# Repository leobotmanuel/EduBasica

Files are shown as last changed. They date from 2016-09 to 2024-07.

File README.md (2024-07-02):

# EduBasica


EDUBASICA es una tarjeta de prototipado rápido para conectar a Arduino. Incluye componentes electrónicos básicos para gran variedad de prácticas y proyectos. Es una tarjeta multipropósito con componentes electrónicos incluidos que puedes usar para fabricar un robot, controlar un sistema de poleas, activar barreras, comunicar dispositivos bluetooth, y todo lo que te puedas imaginar.

 www.arduino.org -- www.arduino.cc

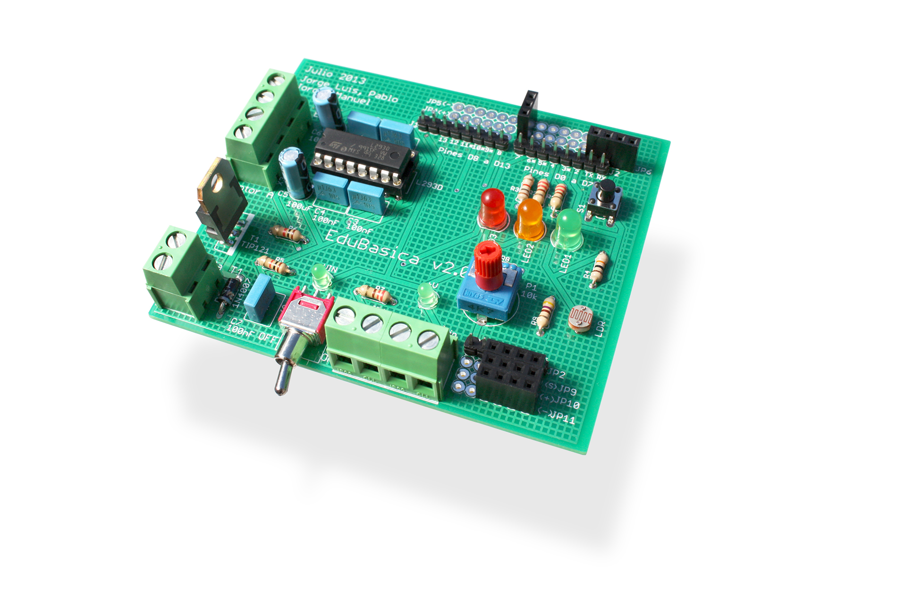
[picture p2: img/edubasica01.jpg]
 EduBasica -- www.practicasconarduino.com

# Conexiones EduBasica con Arduino

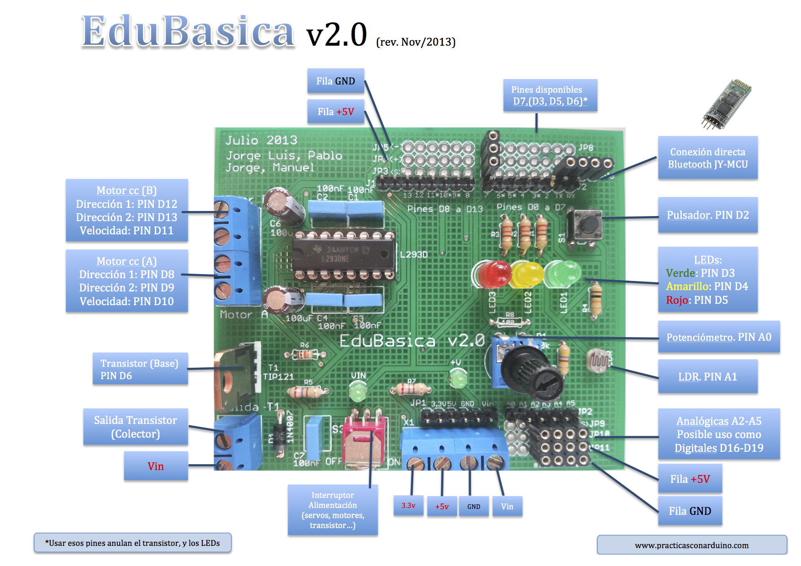
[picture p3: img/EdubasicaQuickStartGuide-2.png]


# Prácticas de programación y electrónica 
# con Arduino-EduBasica

Archivo en pdf de 4ºESO

https://www.dropbox.com/s/mtubbro328of7fd/PracticasConArduino2-2.pdf?dl=0
# Autores
Pablo E. García -- https://www.linkedin.com/in/pablo-evaristo-garc%C3%ADa-palacios-083a5483

Manuel Hidalgo -- https://es.linkedin.com/in/manuel-hidalgo-díaz-b95b467b

Jorge Luis Loza -- https://es.linkedin.com/in/jorgeluisloza

Jorge Muñoz -- https://es.linkedin.com/in/jorge-mu%C3%B1oz-8a641160/es

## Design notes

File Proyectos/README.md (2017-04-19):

# Proyectos con EduBasica


En esta sección tenemos proyectos con EduBasica-Arduino.
# Maqueta de Control de barrera de parking
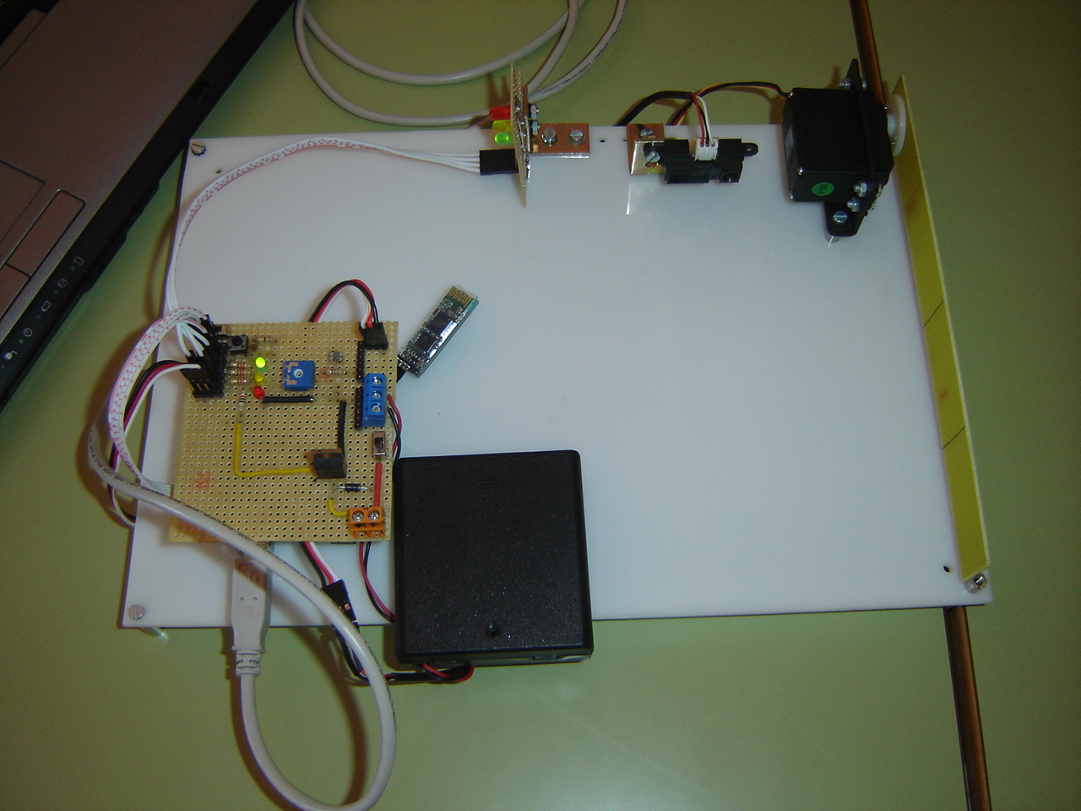
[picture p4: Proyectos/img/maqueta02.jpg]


Este proyecto es una actualización del realizado en el Taller de Robótica Educativa en el IES Pintor Rafael Requena de Caudete-Albacete en el curso 2011-2012.

Video: https://www.youtube.com/watch?v=ucT549aUI94

Presentación: http://platea.pntic.mec.es/~mhidalgo/page5.html

Acceso a la actualización: https://github.com/leobotmanuel/EduBasica/blob/master/Proyectos/controlBarreraParking/README.md
# Maqueta de Control de temperatura
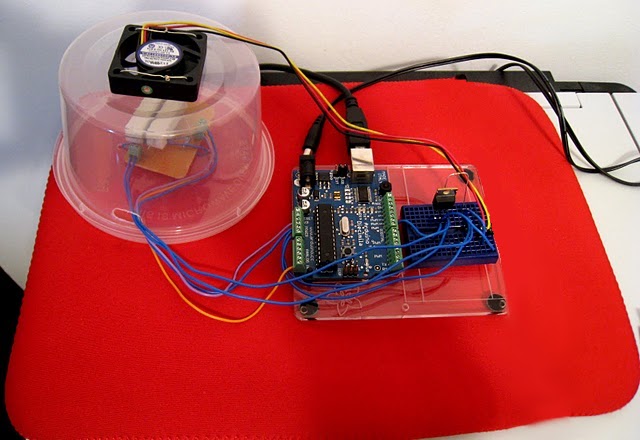
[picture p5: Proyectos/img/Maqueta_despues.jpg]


Este proyecto se basa en la colaboración de Igor R., Alberto Yedra y LeoBot (Manuel) por la fecha de julio del 2011 en la Campus Party de Valencia.

Fuente: http://real2electronics.blogspot.com.es/2011/07/maqueta-de-control-pid-con-arduino.html
# Robot imprimibles
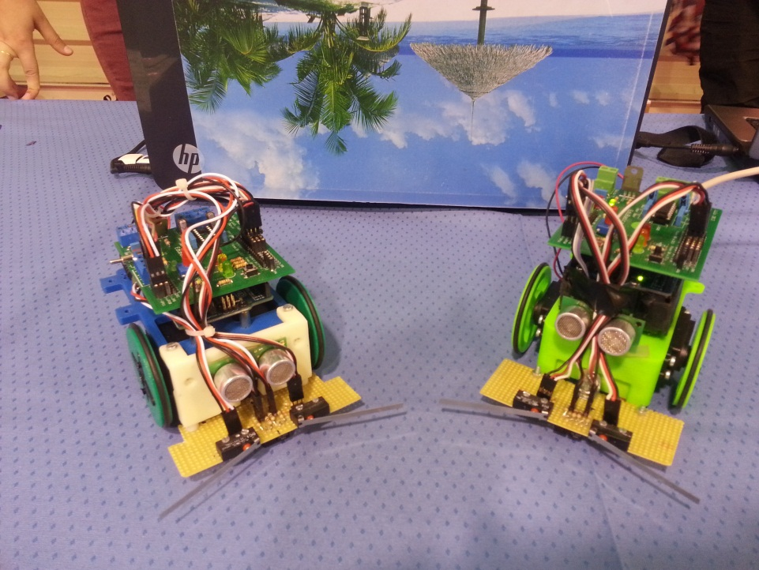
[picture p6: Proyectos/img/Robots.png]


Proyectos de robots imprimibles que tanta aceptación ha tenido en el aula como trabajo para desarrollar los contenidos de electrónica, control, programación y documentación digital.

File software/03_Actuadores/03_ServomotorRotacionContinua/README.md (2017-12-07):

# Servomotor de rotación continua
El servomotor de rotación continua es un servomotor que gira 360º, la velocidad y sentido de giro es controlada por la señal PWM (modulada por anchura de pulso) generada por un microcontrolador.

Señal de control PWM.

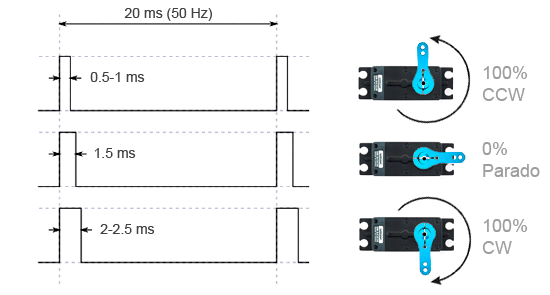
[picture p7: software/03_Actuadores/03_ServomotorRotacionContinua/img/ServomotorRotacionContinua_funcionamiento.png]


Velocidad del servomotor de rotación continua. 

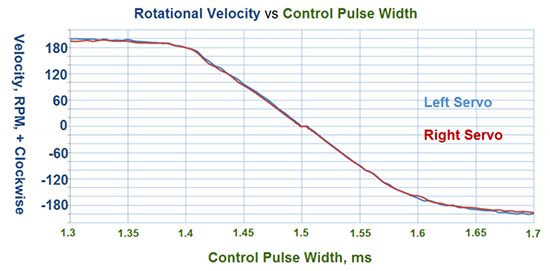
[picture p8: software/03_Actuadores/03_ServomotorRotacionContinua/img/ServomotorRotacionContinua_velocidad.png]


Fuente: [Luis LLamas](https://www.luisllamas.es/controlar-un-servo-de-rotacion-continua-con-arduino)

El servomotor de rotación continua tiene los mismos elementos que el servomotor, diferenciandose sólo en que la resistencia variable es fija. Este cambio hace que se llame "servomotor trucado".

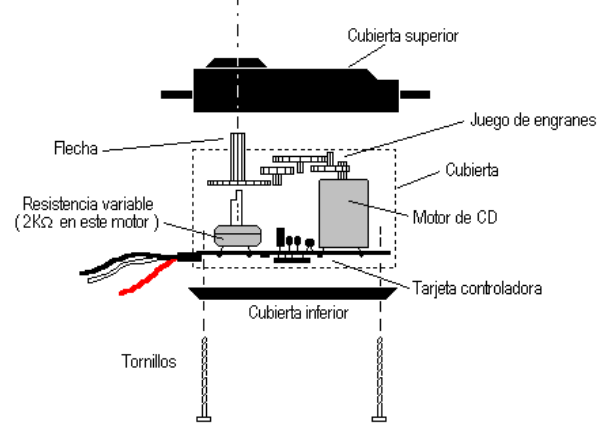
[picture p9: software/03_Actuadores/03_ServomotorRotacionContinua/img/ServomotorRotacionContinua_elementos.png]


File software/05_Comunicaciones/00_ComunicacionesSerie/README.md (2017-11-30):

# Comunicaciones. Puerto serie (USB)
El puerto serie de Arduino se usa para transmitir y recibir datos de otros dispositivos como un PC, teléfono móvil, tablet o microcontrolador.

El puerto serie del Arduino Uno usa los pins 0(RX) y 1(TX). Estos están conectados al controlador FTDI (ATmega 16u2) que es el que permite la traducción del formato serie TTL a USB. Estos pins no pueden ser utilizados mientras se usa la comunicación serie.
Más información del [puerto serie](http://diymakers.es/usando-el-puerto-serie-del-arduino/), la tabla de códigos ASCII se encuentra en la información.

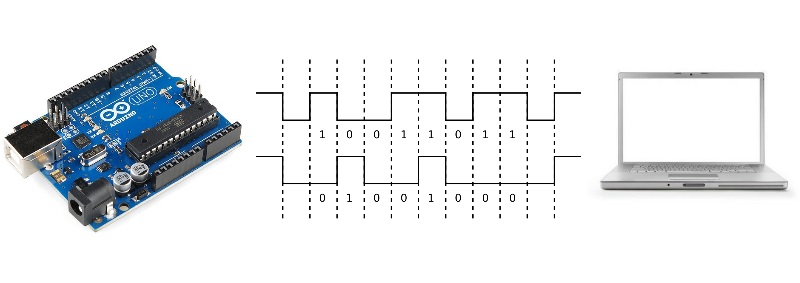
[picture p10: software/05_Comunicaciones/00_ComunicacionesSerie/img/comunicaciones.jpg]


Los programas para aprender el funcionamiento de las comunicaciones por el puerto serie. Son el mismo programa peero con diferente
estructura de control.
- prog11_serie01.bly
- prog11_serie01b.bly

# Actividad
- Añadid las instrucciones necesarias para controlar todos los leds por el puerto serie.

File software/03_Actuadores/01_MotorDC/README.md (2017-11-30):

# Motores de corriente continua
Los motores de corriente continua (motores DC) son unos de los actuadores más utilizados en Robótica Educativa. 
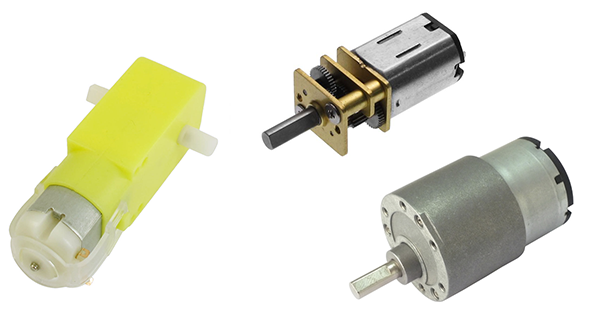
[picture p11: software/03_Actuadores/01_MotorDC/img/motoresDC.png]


Su funcionamiento se basa en el alineamiento de dos campos magnéticos. 
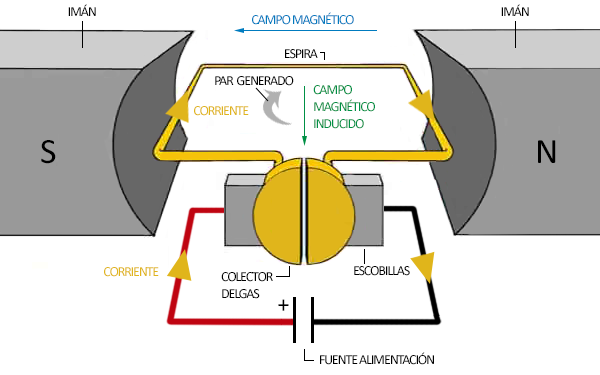
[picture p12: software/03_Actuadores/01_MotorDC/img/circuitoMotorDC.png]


Fuente: [Luis LLamas](http://www.luisllamas.es/2016/08/tipos-motores-rotativos-proyectos-arduino/)

Con EduBasica se puede controlar dos motores DC, utilizando el circuito integrado L293.

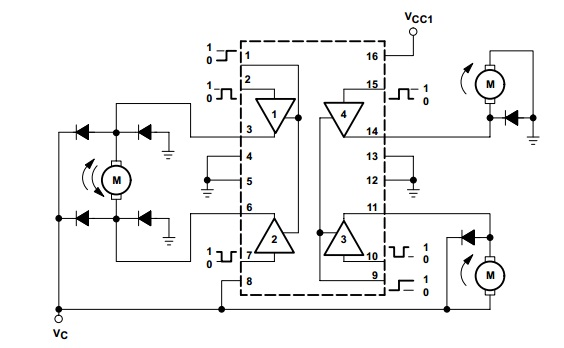
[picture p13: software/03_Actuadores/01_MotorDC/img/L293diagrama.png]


[Más información:](https://learn.adafruit.com/adafruit-arduino-lesson-15-dc-motor-reversing?view=all)

Los programa para aprender su funcionamiento con EduBasica:
- prog08_motorA01.bly
- prog08_motorA02.bly
- prog08_motorA03.bly
- prog08_motorA4.bly

# Actividad

- Modificad y añadid el programa prog08_motorA4.bly para que se encienda el led verde cuando avanza, el led rojo cuando retrocede y el amarillo parpadee cuando esté parado.

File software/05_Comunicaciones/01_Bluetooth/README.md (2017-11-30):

# Bluetooth
El Bluetooth es un estándar de comunicación inalámbrica que permite la transmisión de datos a través de radiofrecuencia en la banda de 2,4 GHz. 

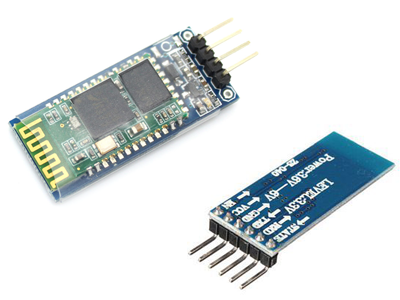
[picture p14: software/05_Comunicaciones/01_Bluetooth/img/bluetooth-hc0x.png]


El módulo de bluetooth en EduBasica se conecta en un zócalo de 4 pines.
-    El pin de transmisión del Bluetooth Tx se conecta al de recepción de Arduino Rx.
-    El pin de recepción del Bluetooth Rx se conecta al de transmisión de Arduino Tx.
-    El pin Vcc del Bluetooth al (+).
-    El pin GND del Bluetooth al (-)
**IMPORTANTE:**
En el momento de cargar el programa desde el Visualino a la placa Arduino hay que desconectar el módulo de Bluetooth para que no interfiera.

Para ello utilizaremos un módulo HC-06 para Arduino y la aplicación para Android Bluecontrol.

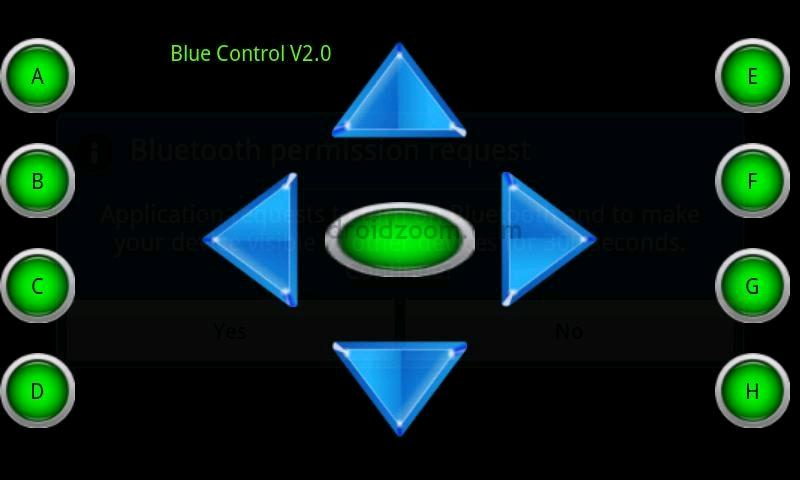
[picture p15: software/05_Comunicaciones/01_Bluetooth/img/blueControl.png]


Ambos dispositivos, módulo Bluetooth y telefóno móvil o tablet, se tienen que emparejar y compartir una contraseña para que los datos puedan intercambiarse. Por defecto, estos módulos tienen la contraseña 1234. Normalmente el módulo de bluetooth tiene un LED que parpadea cuando se está intentando conectar con el móvil. Una vez hecho, la luz del LED permanece fija.

El programa, que tenemos que cargar en Arduino, para aprender su funcionamiento con Visualino:

- prog11_bluetooth.bly

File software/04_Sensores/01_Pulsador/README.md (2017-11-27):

# Pulsador, sensor digital.
El pulsador es un objeto tecnológico simple y nos da dos niveles de tensión alto (HIGH) y bajo (LOW).

El pulsador en EduBasica se utiliza para aprender a leer las [entradas digitales](https://www.luisllamas.es/entradas-digitales-en-arduino/), que tiene el estado de activo (1, lógico)
o no activo (0, lógico) como son: final de carrera, sensor de presencia, sensor a distancia determinada,...

El circuito del pulsador en EduBasica es el siguiente:

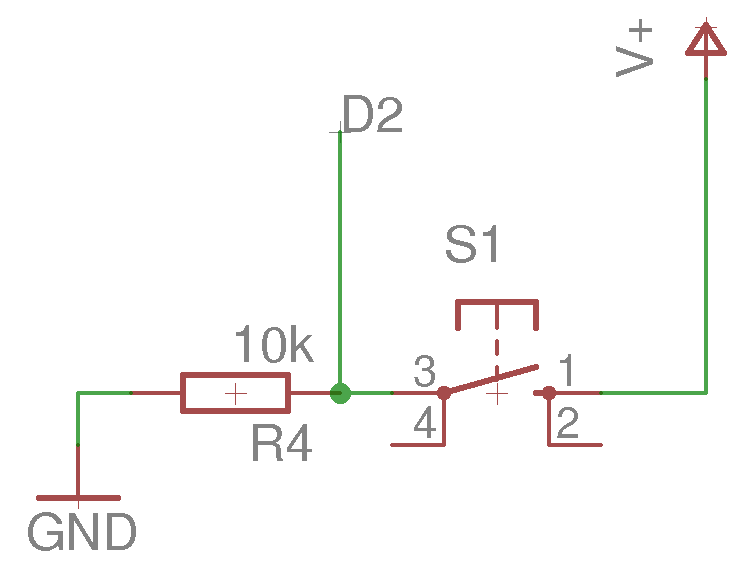
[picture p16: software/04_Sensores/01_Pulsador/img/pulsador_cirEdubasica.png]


El programa para observar su funcionamiento con Visualino:

- prog03_Pulsador.bly

Observad y comprobad que:

- Si el pulsador no está pulsador el LED rojo está apagado.

- Si el pulsador está pulsado el LED rojo está encendido.

# Actividad
Modificad las dos estructuras de control **if**, en el prog03_pulsador.bly, por una estructura de control **if-else**.

Más información [wwww.luisllamas.com](https://www.luisllamas.es/leer-un-pulsador-con-arduino/)

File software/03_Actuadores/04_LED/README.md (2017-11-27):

# LED, actuador de salida luminoso.
El LED es un objeto tecnológico simple luminoso que permite dar información de un evento si está activado o desactivado.
Para más información de su funcionamiento y precauciones a tener en cuenta, consultad [aquí](https://www.luisllamas.es/encender-un-led-con-arduino/)

El LED en EduBasica se utiliza para aprender a programar las [salidas digitales](https://www.luisllamas.es/salidas-digitales-en-arduino/)

El circuito de los LEDs en EduBasica es el siguiente:

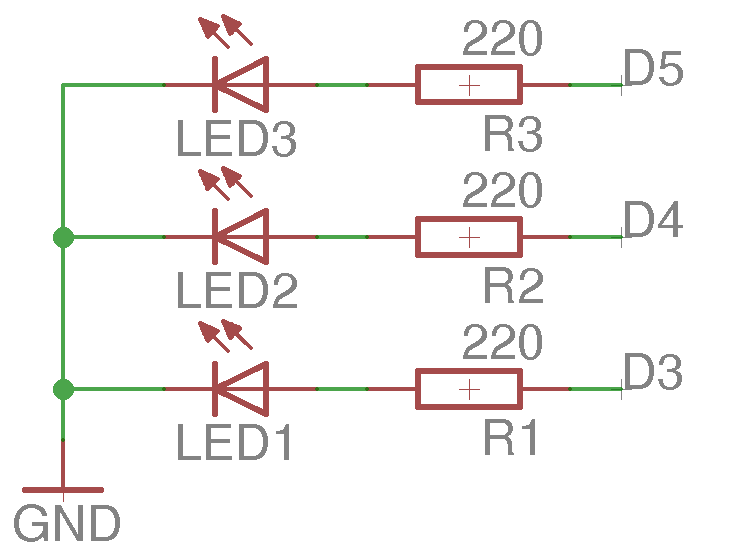
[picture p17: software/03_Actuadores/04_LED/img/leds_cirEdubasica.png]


El programa para aprender a programar las salidas digitales con Visualino:

- prog01_Parpadeo.bly
- prog02_Secuencia.bly

# Actividad
Modificad los programas anteriores para crear secuencias diferentes.

Web de ampliación de información [www.luisllamas.es](https://www.luisllamas.es)

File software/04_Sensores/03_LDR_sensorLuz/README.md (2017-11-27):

# LDR (light-dependent resistor) sensor de luz
El sensor LDR es un sensor resistivo (fotoresistor), es decir que su resistencia eléctrica varía en función de la luz que recibe.
Es un sensor analógico por lo que, para leer sus medidas, tenemos que conectarlo a una entrada analógica de Arduino.
Si tapamos o acercamos el sensor a la luz veremos cómo cambian las medidas a través del monitor serie. 
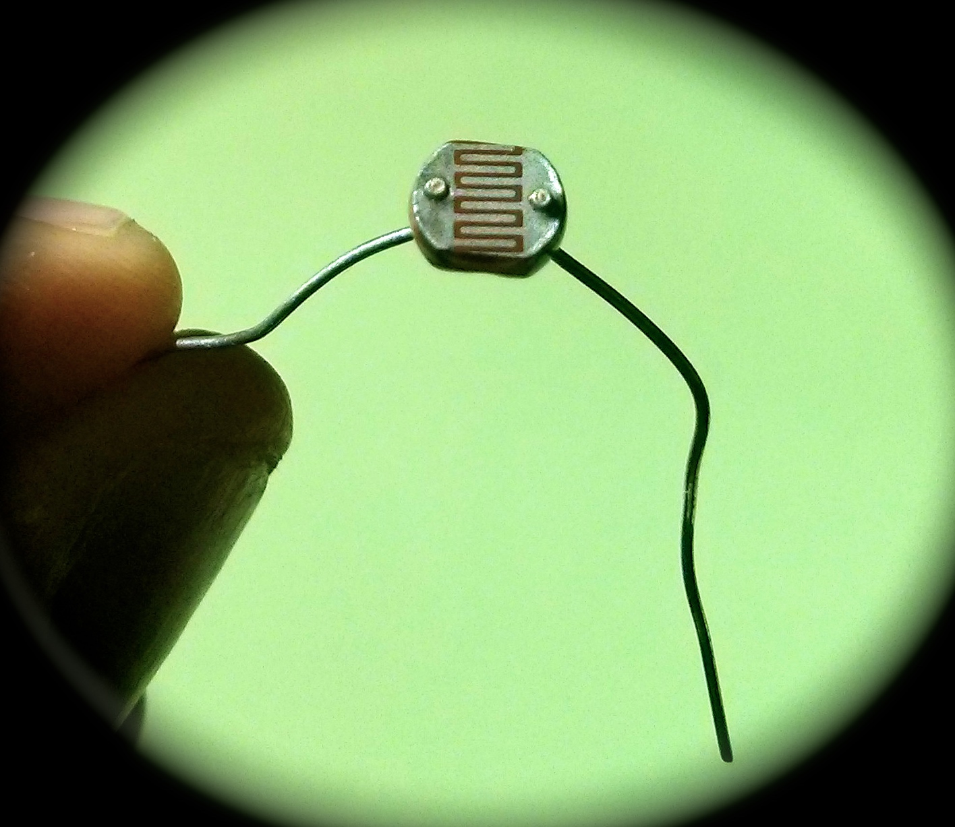
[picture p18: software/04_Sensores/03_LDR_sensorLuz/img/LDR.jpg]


El circuito del sensor LDR en EduBasica es el siguiente:

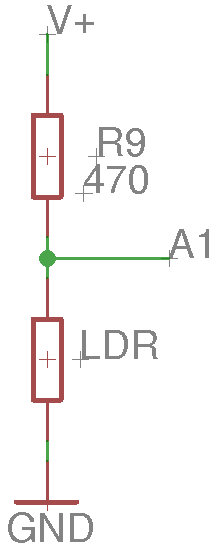
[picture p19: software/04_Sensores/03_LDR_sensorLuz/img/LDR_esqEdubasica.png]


El programa para observar su funcionamiento con Visualino:

- prog06_sensorLDR.bly

A través del monitor serie se comprueba que:

- Si recibe luz el valor leído es bajo.

- Si no recibe luz el valor leído es alto.

# Actividad
Programar el encendido de un led con el LDR (simulación día-noche).

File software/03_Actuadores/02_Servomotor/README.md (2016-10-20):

# Servomotor
El servomotor es un actuador muy utilizado en los proyectos de robótica. 
Un servomotor recibe una señal PWM (modulada por anchura de pulso) generada por un microcontrolador, que posiciona el eje del
servomotor mediante su electrónica de control en un ángulo determinado.

Señal de control PWM.

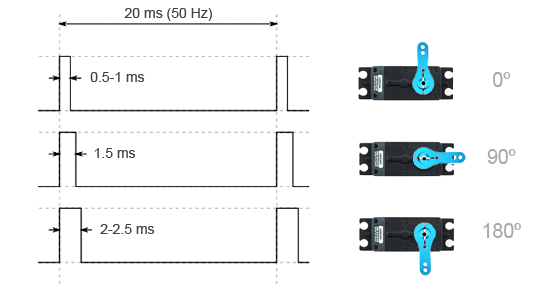
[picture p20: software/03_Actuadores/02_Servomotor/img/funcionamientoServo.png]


Tipos de servomotores. 

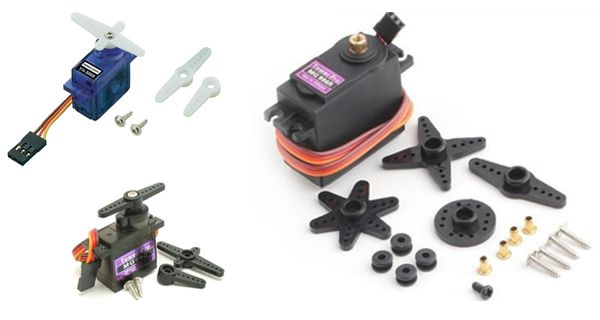
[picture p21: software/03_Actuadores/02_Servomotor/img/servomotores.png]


Elementos de servomotores.

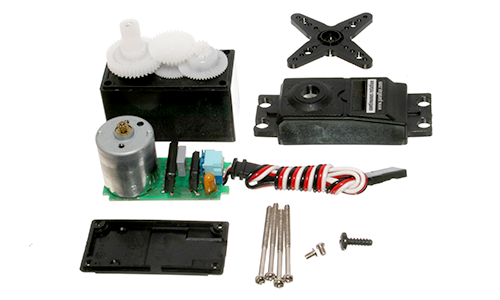
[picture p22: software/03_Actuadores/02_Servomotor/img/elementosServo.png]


Fuente: Luis LLamas
http://www.luisllamas.es/2016/08/tipos-motores-rotativos-proyectos-arduino/

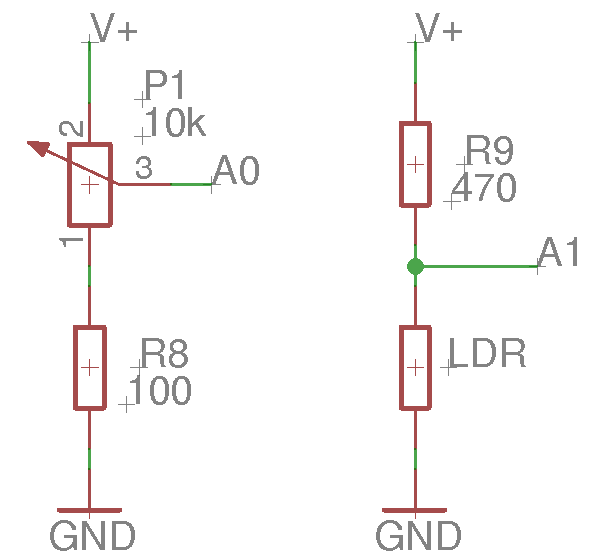
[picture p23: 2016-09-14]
esquemas/img/EntradasAnalogicas.png

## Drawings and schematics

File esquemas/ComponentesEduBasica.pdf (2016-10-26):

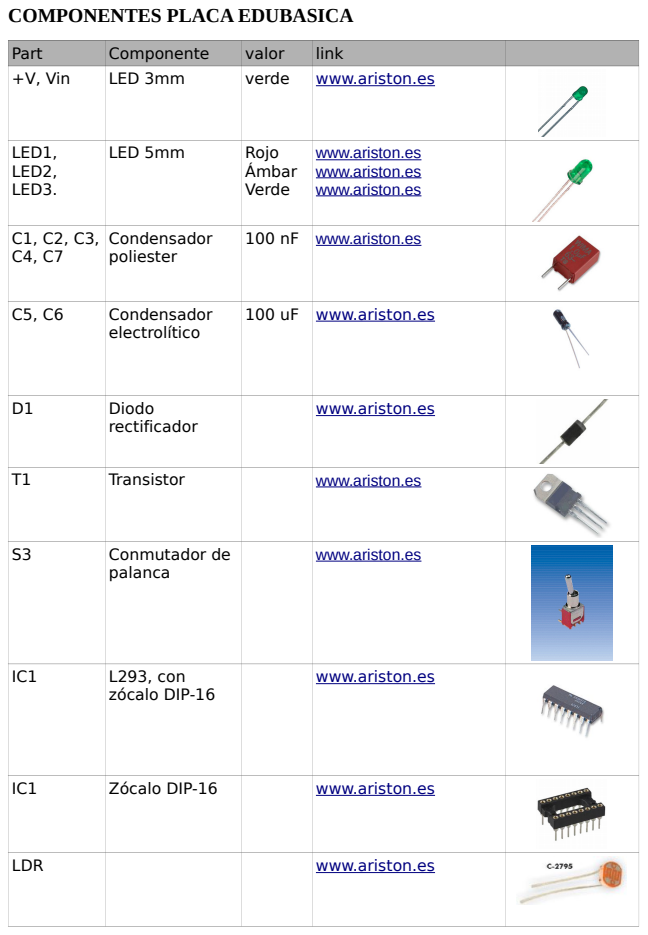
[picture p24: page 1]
Part; Componente; valor; link; +V, Vin; LED 3mm; verde; www.ariston.es; LED1, LED2, LED3.; LED 5mm; Rojo; Ámbar Verde; Condensador poliester; Condensador; electrolítico; Diodo; rectificador; Transistor; Conmutador de; palanca; L293, con; zócalo DIP-16; Zócalo DIP-16; LDR

COMPONENTES PLACA EDUBASICA

www.ariston.es (http://www.ariston.es/producto/l1503it-rohs-kingbright-led-rojo-5mm-32-200mcd-27576.aspx)
www.ariston.es (http://www.ariston.es/producto/l456byd-rohs-diodo-led-intermitente-amarillo-5mm-25150.aspx)
www.ariston.es (http://www.ariston.es/producto/l53gd12-rohs-kingbright-led-verde-12v-5mm-5-32mcd-24086.aspx)

100 nF www.ariston.es (http://www.ariston.es/producto/wh100k100-rohs-wima-mks2-100nf-100v-10-r-5mm-polies-metal-radial-26507.aspx)

100 uF www.ariston.es (http://www.ariston.es/producto/jm100u16-rohs-cond-mini-elec-rad-85c-16v-100uf-6x7-r-25-23860.aspx)

www.ariston.es (http://www.ariston.es/producto/1n4007hb-rohs-1n4007-do-41-1a-1000v-rectifier-diode-hy-46159.aspx)

www.ariston.es (http://www.ariston.es/producto/it0610-rohs-conm-sub-mini-acodado-palanca-2p-1c-on-none-on-ci-13305.aspx)

www.ariston.es

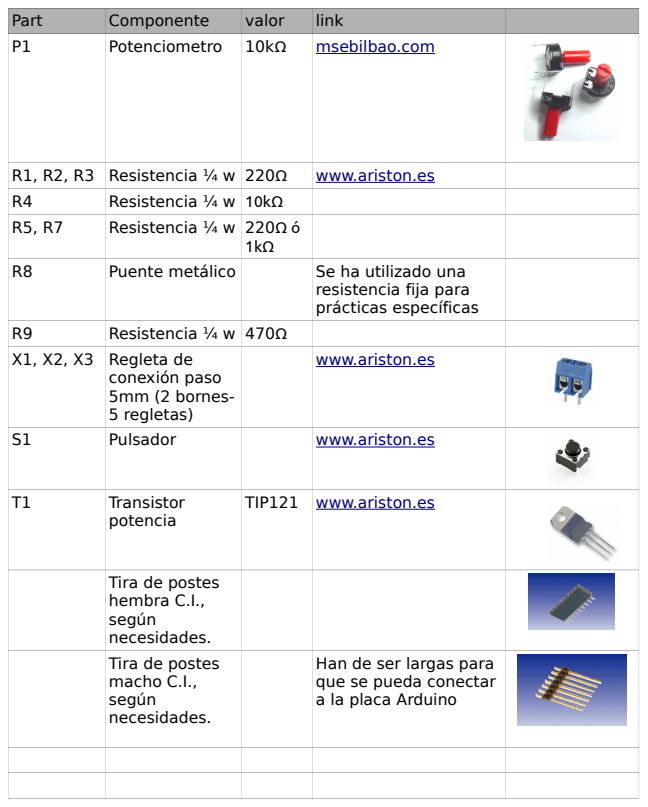
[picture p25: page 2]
Part; Componente; valor; link; Potenciometro; msebilbao.com; R1, R2, R3 Resistencia ¼ w 220Ω; www.ariston.es; Resistencia ¼ w 10kΩ; Resistencia ¼ w 220Ω ó; Puente metálico; Se ha utilizado una; Resistencia ¼ w 470Ω; X1, X2, X3 Regleta de conexión paso 5mm (2 bornes- 5 regletas); Pulsador; Transistor; potencia

resistencia fija para
prácticas específicas

www.ariston.es (http://www.ariston.es/productos/buscar.aspx?cat=2477)

TIP121 www.ariston.es (http://www.ariston.es/producto/tip121-rohs-st-npn-darl-nfs-l-80v-5a-65w-b1000-to-220-20787.aspx)

Tira de postes
hembra C.I.,
según
necesidades.
macho C.I.,

Han de ser largas para
que se pueda conectar
a la placa Arduino

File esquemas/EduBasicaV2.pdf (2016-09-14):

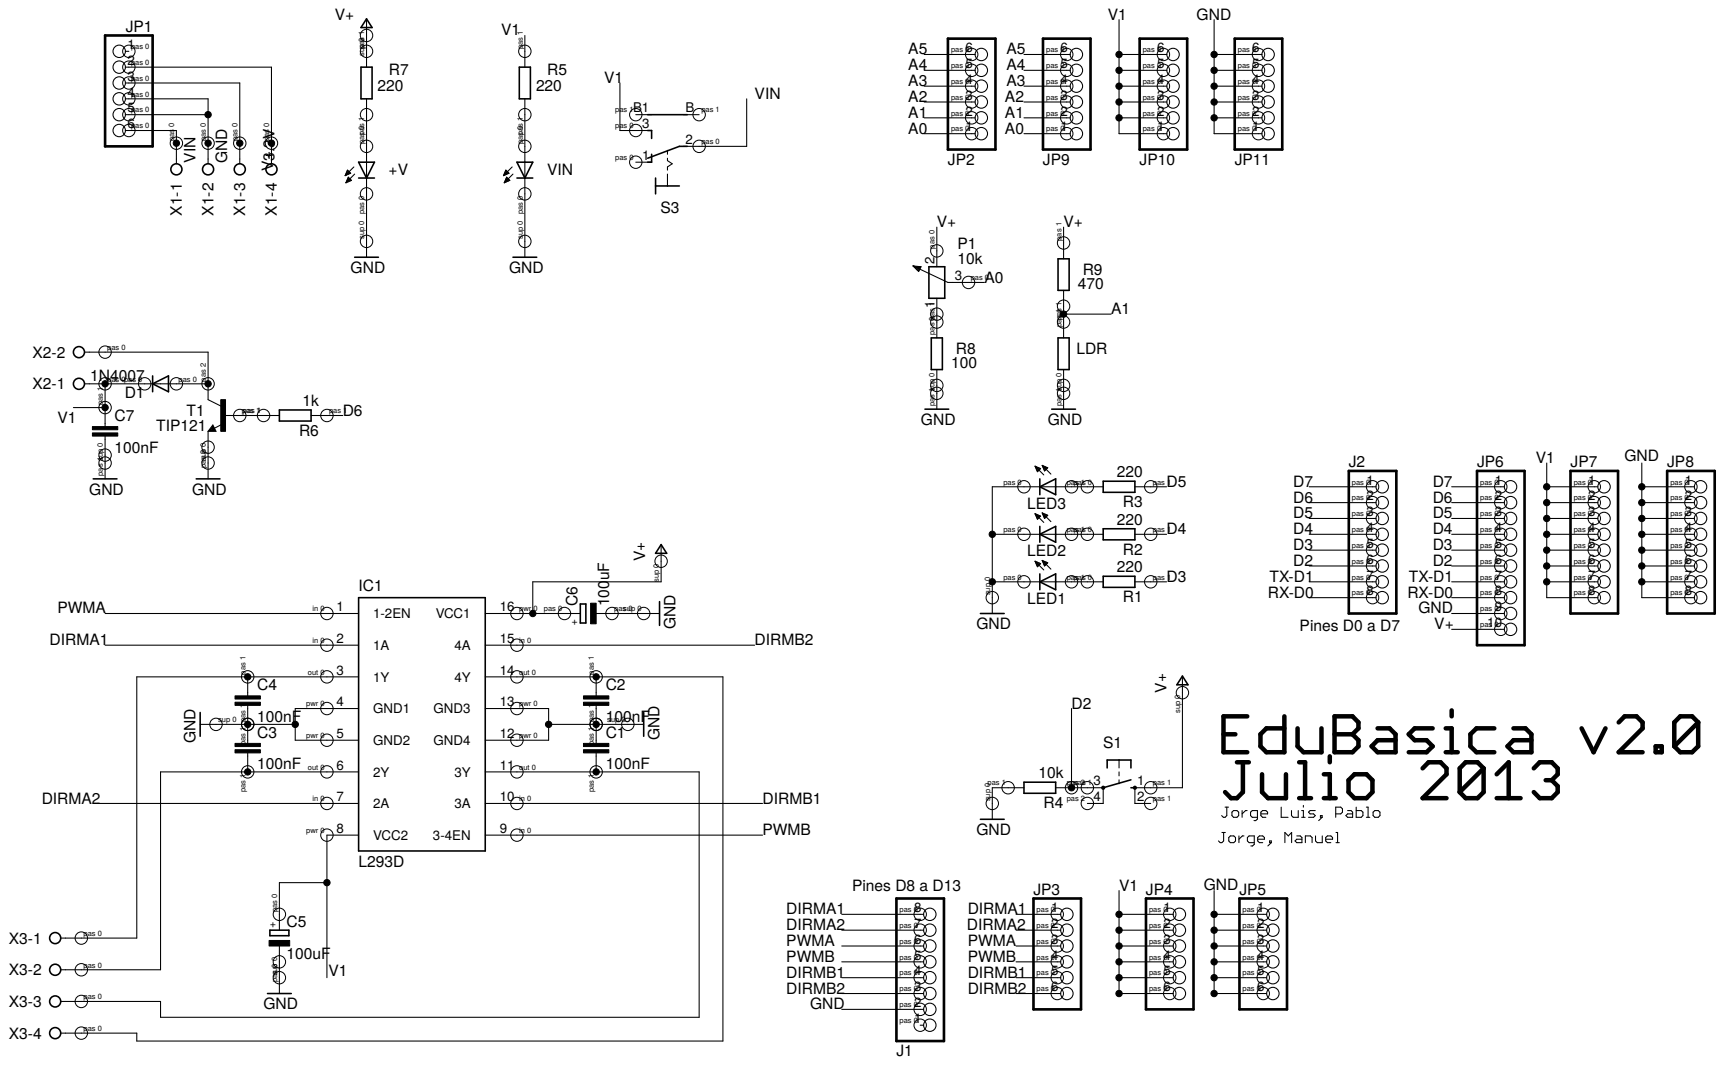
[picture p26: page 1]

sup 0 sup 0 pas 1 pas 1 pas 0 pas 0

sup 0 pas 1 pas 1 pas 0 pas 0

pas 1 pas 1sup 0 pas 0 pas 0

pas 1 pas 1

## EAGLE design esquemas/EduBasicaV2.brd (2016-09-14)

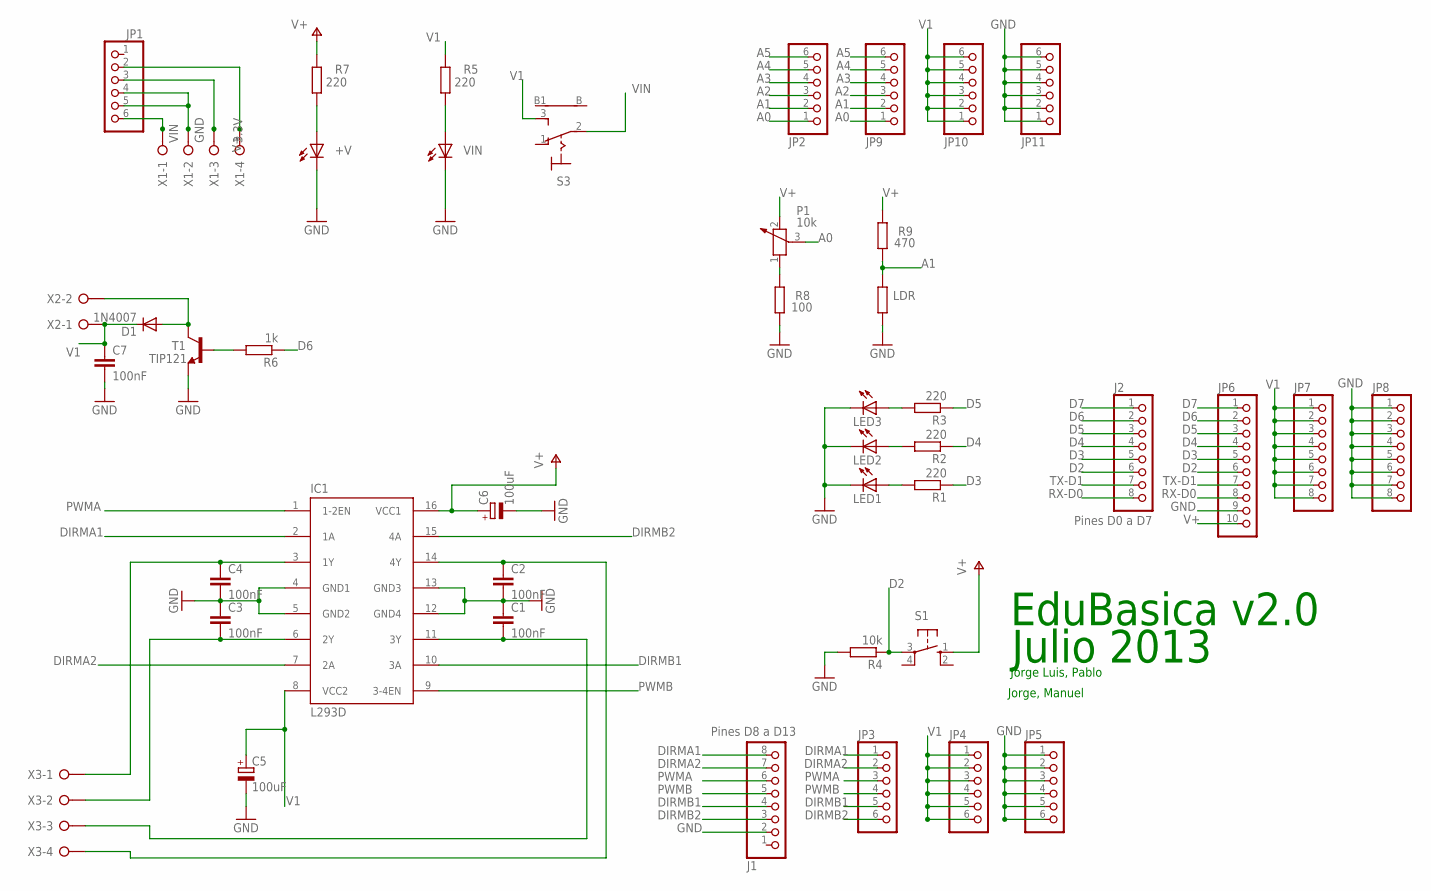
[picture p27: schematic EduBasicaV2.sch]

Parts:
+V: LED3MM
C1, C2, C3, C4, C7: 100nF; C5B5.5
C5, C6: 100uF; E2,5-5
D1: 1N4007; D-7.5
IC1: L293D; DIL16
J1: Pines D8 a D13; 1X08
J2: Pines D0 a D7; 1X08
JP1, JP2, JP3, JP4, JP5, JP9, JP10, JP11: PINHD-1X6; 1X06
JP6: PINHD-1X10; 1X10
JP7, JP8: PINHD-1X8; 1X08
LDR: R-EU_0204/2V; 0204V
LED1, LED2, LED3: LED5MM
P1: 10k; PT-10
R1, R2, R3, R5, R7: 220; 0204/7
R4: 10k; 0204/7
R6: 1k; 0204/7
R8: 100; 0204/7
R9: 470; 0204/7
S1: 10-XX; B3F-10XX
S3: 9070-1W
T1: TIP121; TO220V
VIN: LED3MM
X1, X3: W237-04P; W237-4P
X2: W237-02P; W237-132

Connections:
3.3V: JP1.2, X1.4
A0: JP2.1, JP9.1, P1.3
A1: JP2.2, JP9.2, LDR.2, R9.1
A2: JP2.3, JP9.3
A3: JP2.4, JP9.4
A4: JP2.5, JP9.5
A5: JP2.6, JP9.6
D2: J2.6, JP6.6, R4.1, S1.3
D3: J2.5, JP6.5, R1.1
D4: J2.4, JP6.4, R2.1
D5: J2.3, JP6.3, R3.1
D6: J2.2, JP6.2, R6.1
D7: J2.1, JP6.1
DIRMA1: IC1.2 (1A), J1.8, JP3.1
DIRMA2: IC1.7 (2A), J1.7, JP3.2
DIRMB1: IC1.10 (3A), J1.4, JP3.5
DIRMB2: IC1.15 (4A), J1.3, JP3.6
GND: +V.K (C), C1.1, C2.2, C3.1, C4.2, C5.-, C6.-, C7.2, IC1.4 (GND1), IC1.5 (GND2), IC1.12 (GND4), IC1.13 (GND3), J1.2, JP1.4, JP1.5, JP5.1, JP5.2, JP5.3, JP5.4, JP5.5, JP5.6, JP6.9, JP8.1, JP8.2, JP8.3, JP8.4, JP8.5, JP8.6, JP8.7, JP8.8, JP11.1, JP11.2, JP11.3, JP11.4, JP11.5, JP11.6, LDR.1, LED1.K (C), LED2.K (C), LED3.K (C), R4.2, R8.1, T1.3 (E), VIN.K (C), X1.2
unnamed: R6.2, T1.1 (B)
unnamed: D1.A, T1.2 (C), X2.2
unnamed: P1.1, R8.2
unnamed: R5.1, VIN.A
unnamed: LED3.A, R3.2
unnamed: LED2.A, R2.2
unnamed: LED1.A, R1.2
unnamed: C4.1, IC1.3 (1Y), X3.1
unnamed: C3.2, IC1.6 (2Y), X3.2
unnamed: C1.2, IC1.11 (3Y), X3.3
unnamed: C2.1, IC1.14 (4Y), X3.4
unnamed: +V.A, R7.1
PWMA: IC1.1 (1-2EN), J1.6, JP3.3
PWMB: IC1.9 (3-4EN), J1.5, JP3.4
RX-D0: J2.8, JP6.8
TX-D1: J2.7, JP6.7
V1: C5.+, C7.1, D1.C, IC1.8 (VCC2), JP4.1, JP4.2, JP4.3, JP4.4, JP4.5, JP4.6, JP7.1, JP7.2, JP7.3, JP7.4, JP7.5, JP7.6, JP7.8, JP10.1, JP10.2, JP10.3, JP10.4, JP10.5, JP10.6, R5.2, S3.3 (S), X2.1
V+: C6.+, IC1.16 (VCC1), JP1.3, JP6.10, P1.2, R7.2, R9.2, S1.1 (S), X1.3
VIN: JP1.6, S3.2, X1.1

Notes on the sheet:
EduBasica v2.0
Jorge Luis, Pablo
Jorge, Manuel
Julio 2013

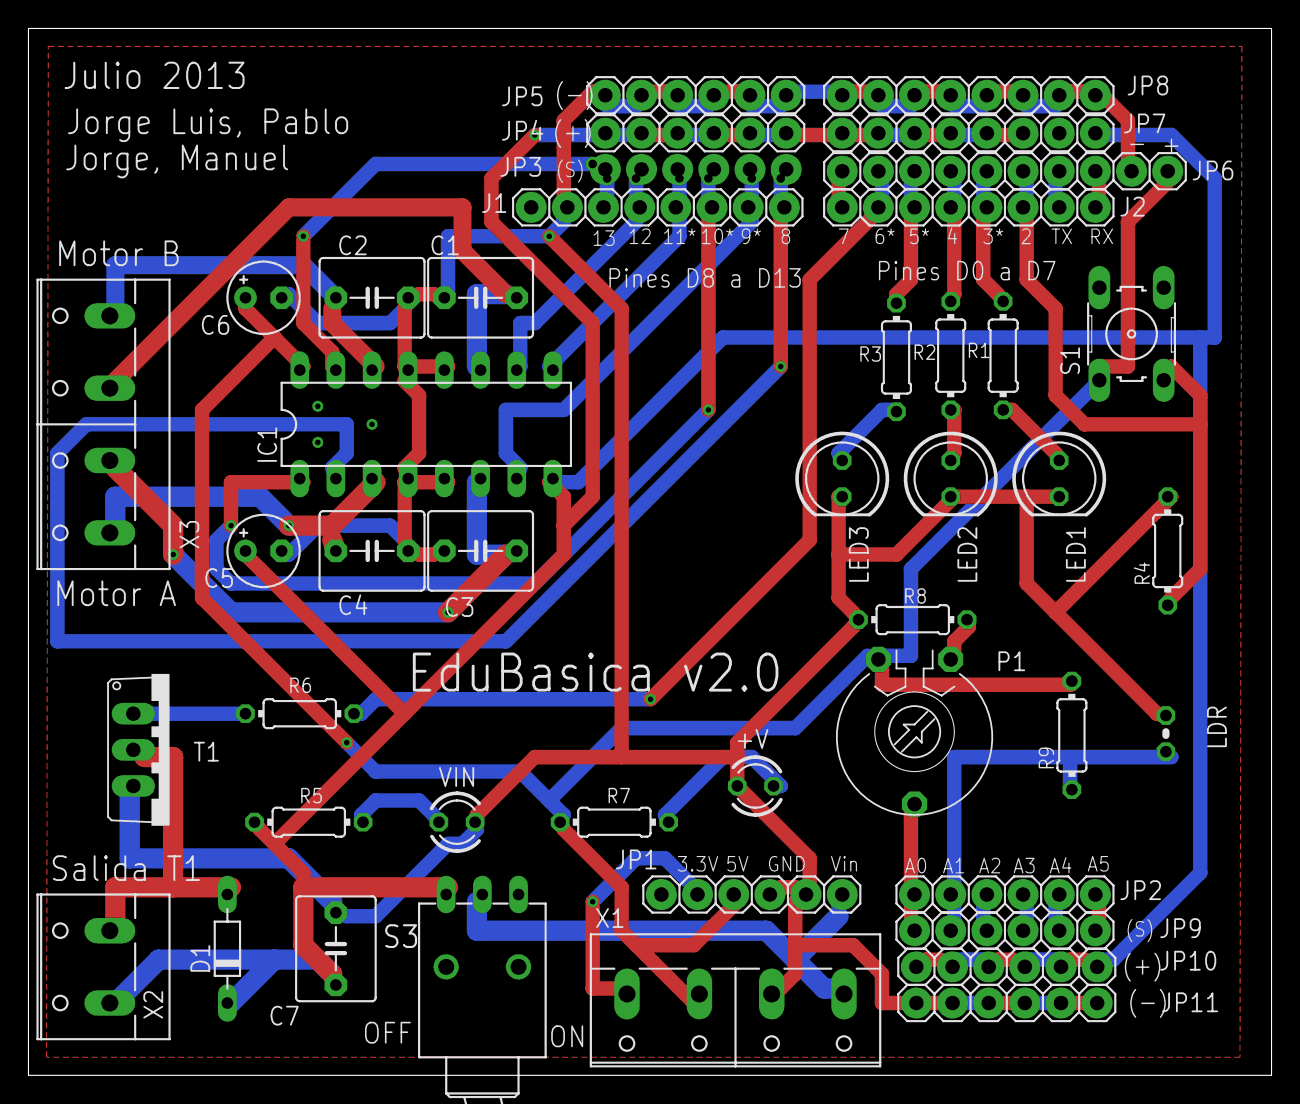
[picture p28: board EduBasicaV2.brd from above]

Board: 2 copper layers, 87.3 x 73.5 mm, 44 parts (1 on the bottom side), 37 nets.

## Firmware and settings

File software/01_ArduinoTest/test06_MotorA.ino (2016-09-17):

/*
  Test del motor A controlado un puente en H
  del C.I. L293D
  Comprueba el funcionamiento del motor A  
  EL INTERRUPTOR DE CORRIENTE DE EDUBASICA TIENE QUE ESTAR EN POSICION ON

////////////////////////////////////////////////////////////
  Sketch Test for motorA controlled by L239D H bridge (600mA)
  THE POWER SWITCH PROVIDEED ON EDUBASICA MUST TO BE ON 
  
  Manuel Hidalgo - LeoBot  Julio 2014
  Pablo Garcia - May 2015
*/


//Etiquetas de identificación de los pines // labels for pins
//pines para controlar la direccion de giro // with 2 pins we control de spinning direction
const int motorA_Dir1 = 8;        
const int motorA_Dir2 = 9;
const int motorA_Velocidad = 10;  //salida PWM para controlar la velocidad // PWM for speed

//Variables
int vPWM = 155;    //valor de la velocidad en PWM // PWM speed

void setup(){
  //configuracion de los pines //pins setup
  pinMode(motorA_Dir1, OUTPUT);
  pinMode(motorA_Dir2, OUTPUT);
  
}

void loop(){
  forward();
  delay(4000);              
  stop();
  delay(2000);
  backw();
  delay(4000); 
  stop();
  delay(2000);  
}

void forward(){
    //Activamos el motor A en un sentido de giro
  //spinning direction 1 (high-low)
  digitalWrite(motorA_Dir1,HIGH);
  digitalWrite(motorA_Dir2,LOW); 
  analogWrite(motorA_Velocidad,vPWM);
}
   
void backw(){
    //Activamos el motor A en un sentido de giro
  //spinning direction 1 (high-low)
  digitalWrite(motorA_Dir1,LOW);
  digitalWrite(motorA_Dir2,HIGH); 
  analogWrite(motorA_Velocidad,vPWM);
}

void stop(){
 //Paramos el motor durante 2s //stop for 2 secs
  //STOP (low, low)
  digitalWrite(motorA_Dir1,LOW);
  digitalWrite(motorA_Dir2,LOW);
}

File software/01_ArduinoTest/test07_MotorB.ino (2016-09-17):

/*
  Test del motor B controlado un puente en H
  del C.I. L293D
  Comprueba el funcionamiento del motor B  
  Manuel Hidalgo - LeoBot
  Julio 2014
*/

//Etiquetas de identificación de los pines
const int motorB_Dir1 = 12;        //pines para controlar la direccion de giro
const int motorB_Dir2 = 13;
const int motorB_Velocidad = 11;  //salida PWM para controlar la velocidad

//Variables
int vPWM = 155;    //valor de la velocidad en PWM

void setup(){
  //configuracion de los pines
  pinMode(motorB_Dir1, OUTPUT);
  pinMode(motorB_Dir2, OUTPUT);
  
}

void loop(){
  //Activamos el motor B en un sentido de giro
  digitalWrite(motorB_Dir1,HIGH);
  digitalWrite(motorB_Dir2,LOW); 
  analogWrite(motorB_Velocidad,vPWM);
  delay(5000);                //permanece activado 5s
  
  //Paramos el motor durante 2 segundo
  digitalWrite(motorB_Dir1,LOW);
  digitalWrite(motorB_Dir2,LOW);
  delay(2000);
  
  //Activamos el motor B en un sentido de giro
  digitalWrite(motorB_Dir1,LOW);
  digitalWrite(motorB_Dir2,HIGH); 
  analogWrite(motorB_Velocidad,vPWM);
  delay(5000);                //permanece activado 5s
  
  //Paramos el motor durante 1 segundo
  digitalWrite(motorB_Dir1,LOW);
  digitalWrite(motorB_Dir2,LOW);
  delay(2000);
}
